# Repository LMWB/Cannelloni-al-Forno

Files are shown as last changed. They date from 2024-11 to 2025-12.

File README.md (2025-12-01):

# Cannelloni-al-Forno
Timer Clock Arduino Shield and C-Library

# Description
I always wanted to use the world famous LD293D motor driver IC. Here I created a very simple application using this chip to build a timer clock that is able to drive some 12V loads.  
Since the LD293D is a THT device and the overall application i quite simple, I decided to build the hole board as THT as it was back in the days :) To give the board a little retro touch I gave the top and bottom layer a hole grid pcb design.  

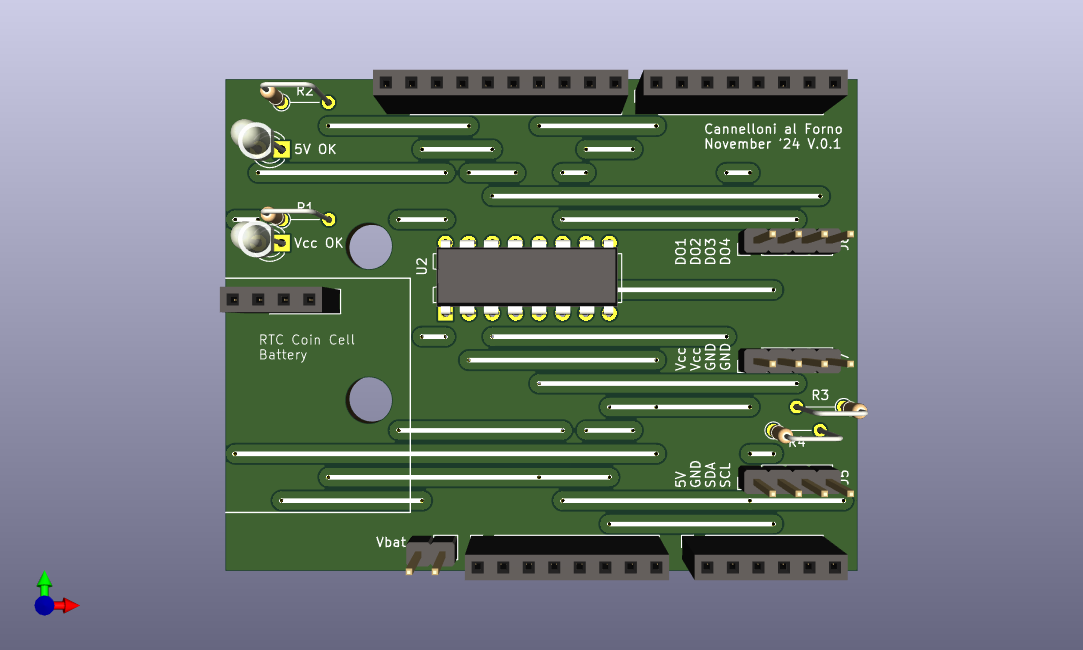
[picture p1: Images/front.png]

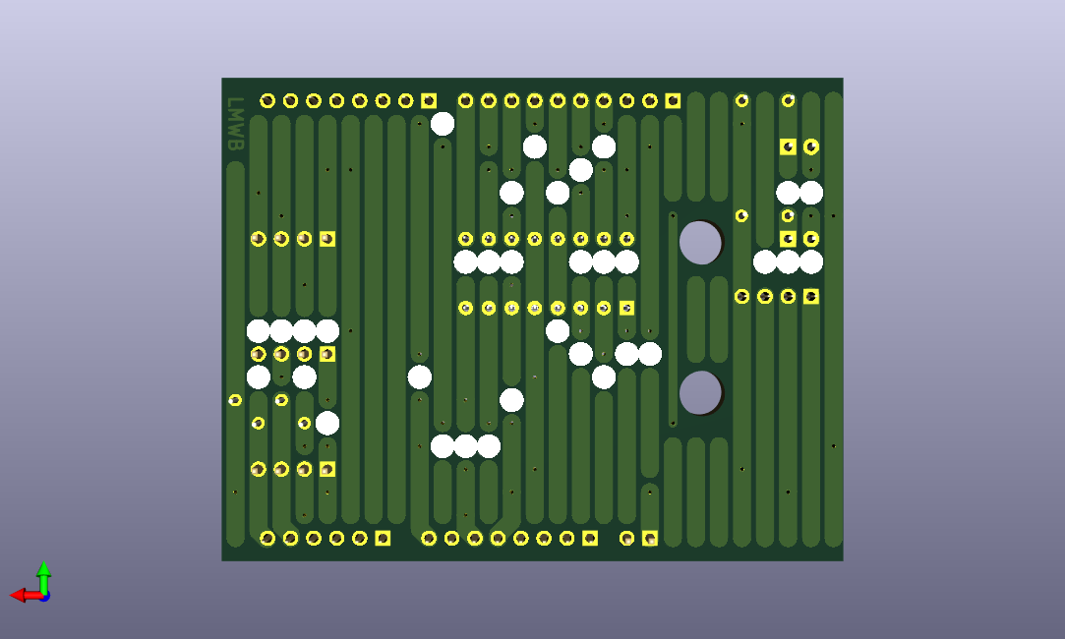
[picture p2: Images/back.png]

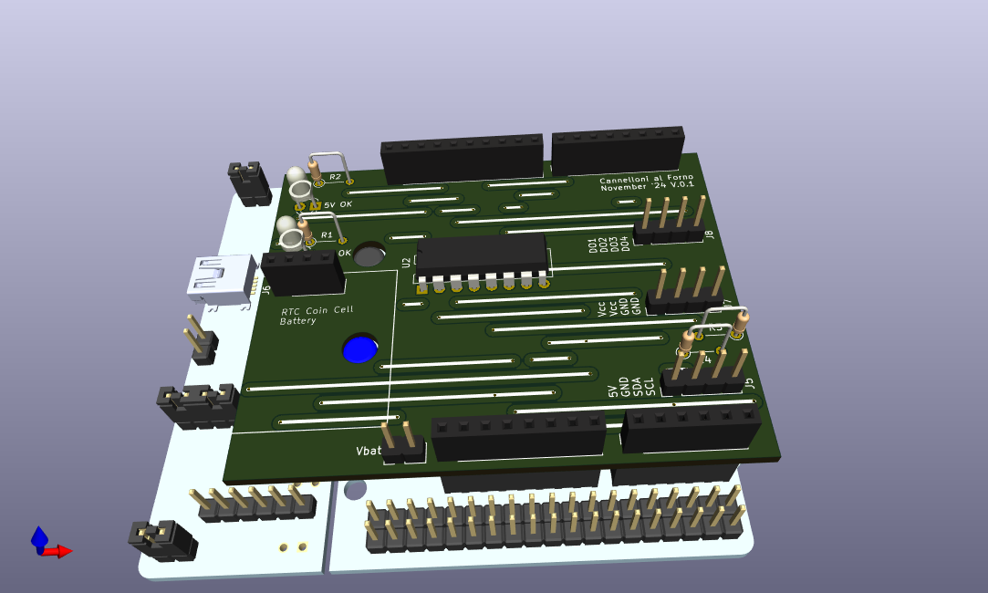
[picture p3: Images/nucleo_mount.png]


# Real World Example
I used the [led constant current driver](https://github.com/LMWB/LED_CC_Driver?tab=readme-ov-file) to create a light for my courtyard.  

todo
- Xmas deciration
- composition of Canneloni-al-Forno and LED_CC_Driver

# Features
- 12V input (powers Nucleo board as well)
- 4 digital outputs (Vout = Vinput)
- RTC with coin cell back up battery

# todo
- add some sort of remote access (wifi, can, RS485,..)
- add shunt to track total energy consumption
- use TI DRV89xx instead of LD293D
- update noRTOS to latest version
- make timerclock multi instance to control different output channels

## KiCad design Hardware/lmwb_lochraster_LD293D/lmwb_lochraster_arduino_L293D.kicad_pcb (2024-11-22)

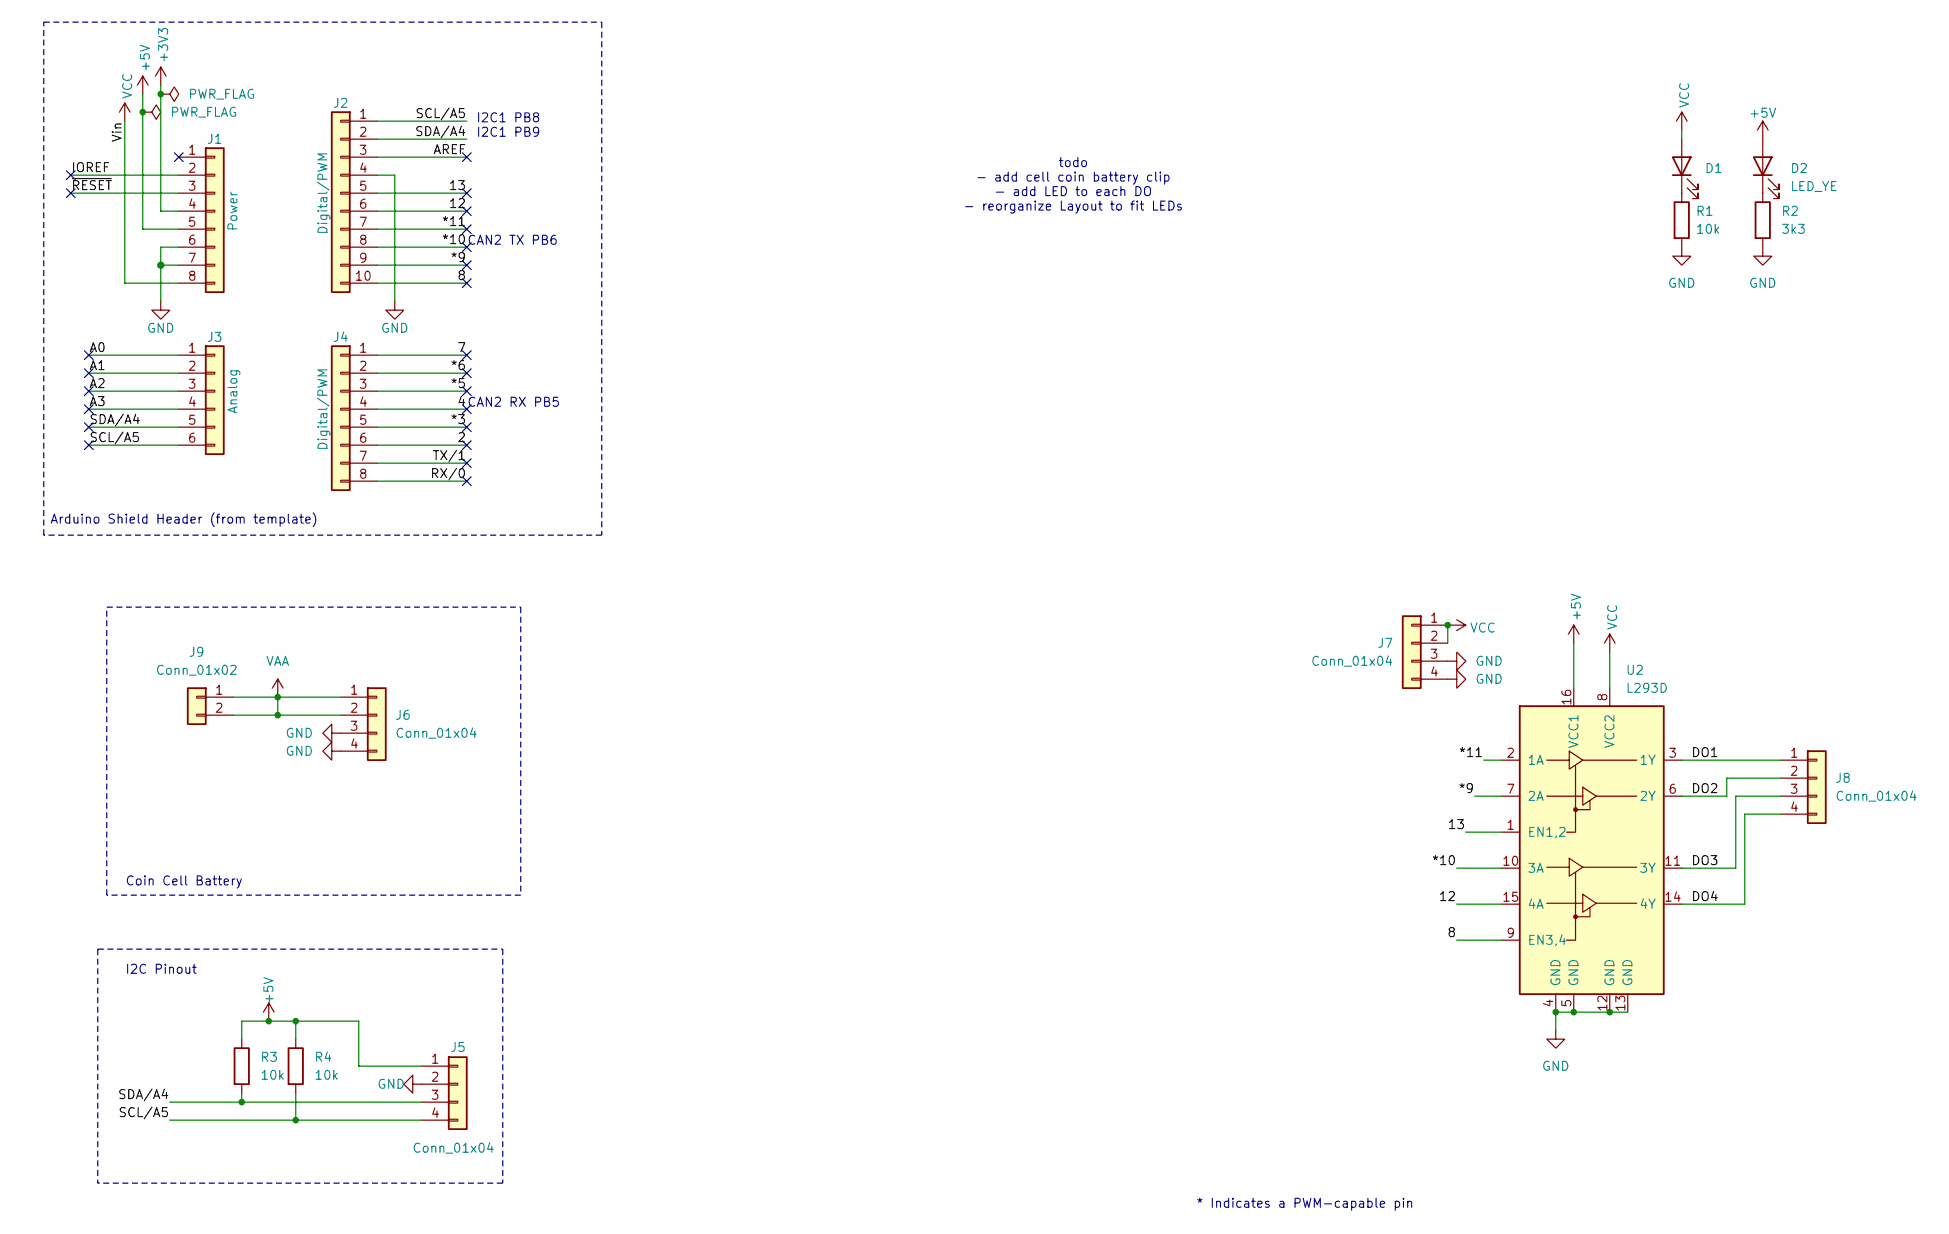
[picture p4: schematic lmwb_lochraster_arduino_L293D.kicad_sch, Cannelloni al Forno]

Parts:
D1, D2: LED_YE; LED_D3.0mm_Clear
J1: Power; PinSocket_1x08_P2.54mm_Vertical
J2: Digital/PWM; PinSocket_1x10_P2.54mm_Vertical
J3: Analog; PinSocket_1x06_P2.54mm_Vertical
J4: Digital/PWM; PinSocket_1x08_P2.54mm_Vertical
J5, J7, J8: Conn_01x04; PinHeader_1x04_P2.54mm_Vertical
J6: Conn_01x04; PinSocket_1x04_P2.54mm_Vertical
J9: Conn_01x02; PinHeader_1x02_P2.54mm_Vertical
R1, R3, R4: 10k; R_Axial_DIN0204_L3.6mm_D1.6mm_P5.08mm_Vertical
R2: 3k3; R_Axial_DIN0204_L3.6mm_D1.6mm_P5.08mm_Vertical
U2: L293D; DIP-16_W7.62mm

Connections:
+3V3: J1.4
+5V: D2.2 (A), J1.5, J5.1, R3.1, R4.1, U2.16 (VCC1)
/2: J4.6
/4: J4.4
/7: J4.1
/8: J2.10, U2.9 (EN3,4)
/12: J2.6, U2.15 (4A)
/13: J2.5, U2.1 (EN1,2)
/*3: J4.5
/*5: J4.3
/*6: J4.2
/*9: J2.9, U2.7 (2A)
/*10: J2.8, U2.10 (3A)
/*11: J2.7, U2.2 (1A)
/A0: J3.1
/A1: J3.2
/A2: J3.3
/A3: J3.4
/AREF: J2.3
/DO1: J8.1, U2.3 (1Y)
/DO2: J8.2, U2.6 (2Y)
/DO3: J8.3, U2.11 (3Y)
/DO4: J8.4, U2.14 (4Y)
/IOREF: J1.2
/RX/0: J4.8
/SCL/A5: J2.1, J3.6, J5.4, R4.2
/SDA/A4: J2.2, J3.5, J5.3, R3.2
/TX/1: J4.7
/~RESET: J1.3
GND: J1.6, J1.7, J2.4, J5.2, J6.3, J6.4, J7.3, J7.4, R1.2, R2.2, U2.4 (GND), U2.5 (GND), U2.12 (GND), U2.13 (GND)
unnamed: D1.1 (K), R1.1
unnamed: D2.1 (K), R2.1
VAA: J6.1, J6.2, J9.1, J9.2
VCC: D1.2 (A), J1.8, J7.1, J7.2, U2.8 (VCC2)

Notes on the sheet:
I2C1 PB8 I2C1 PB9
Coin Cell Battery
CAN2 RX PB5
todo - add cell coin battery clip - add LED to each DO - reorganize Layout to fit LEDs
CAN2 TX PB6
Arduino Shield Header (from template)
I2C Pinout
* Indicates a PWM-capable pin

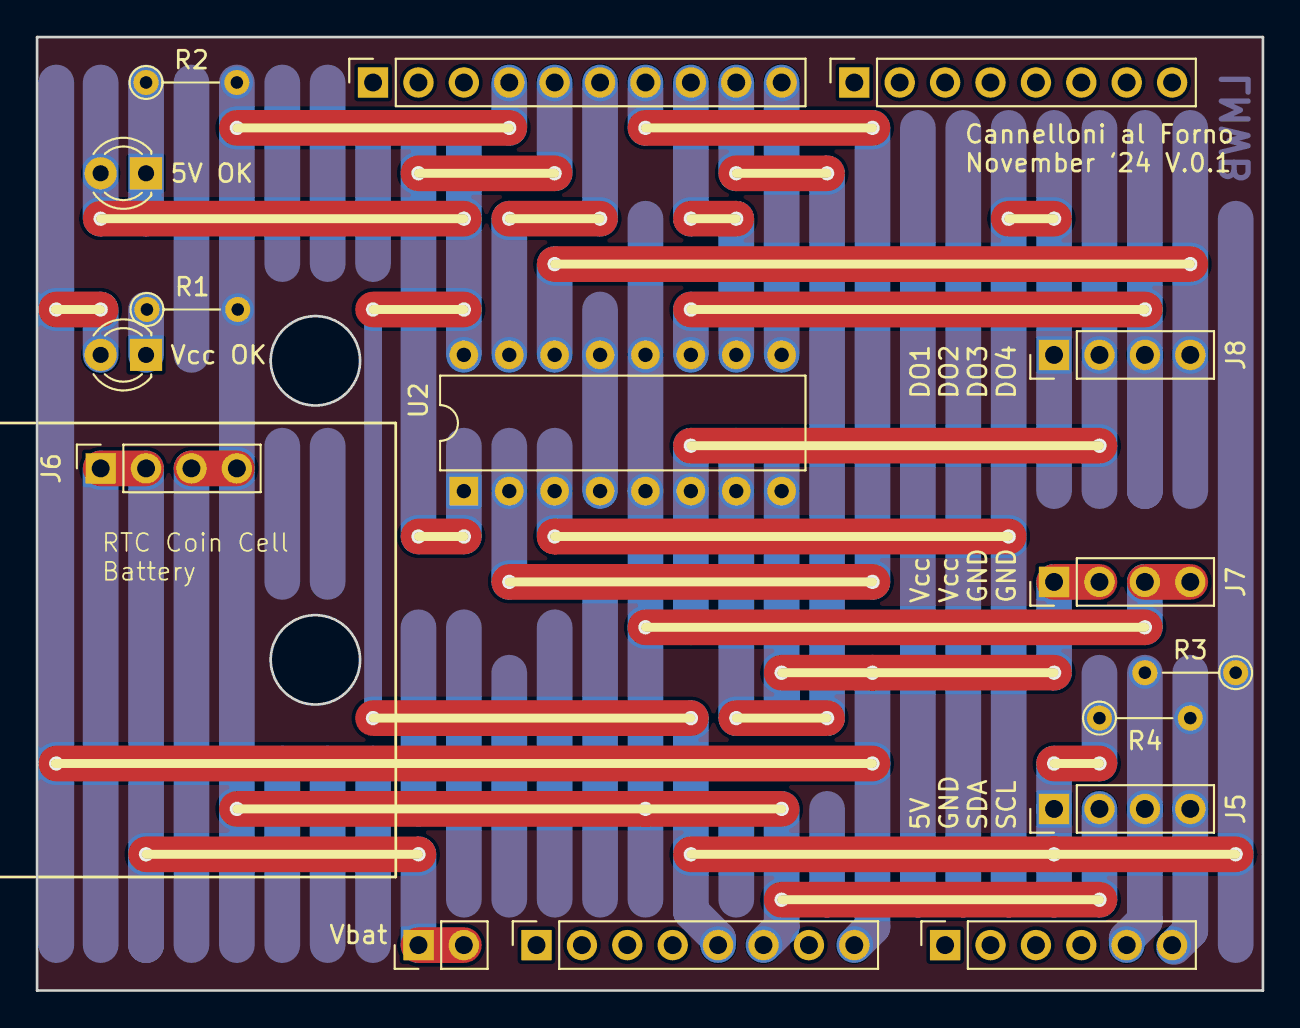
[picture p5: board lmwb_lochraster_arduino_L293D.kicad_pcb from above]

Board: 2 copper layers, 68.6 x 53.3 mm, 16 parts (0 on the bottom side), 18 nets.

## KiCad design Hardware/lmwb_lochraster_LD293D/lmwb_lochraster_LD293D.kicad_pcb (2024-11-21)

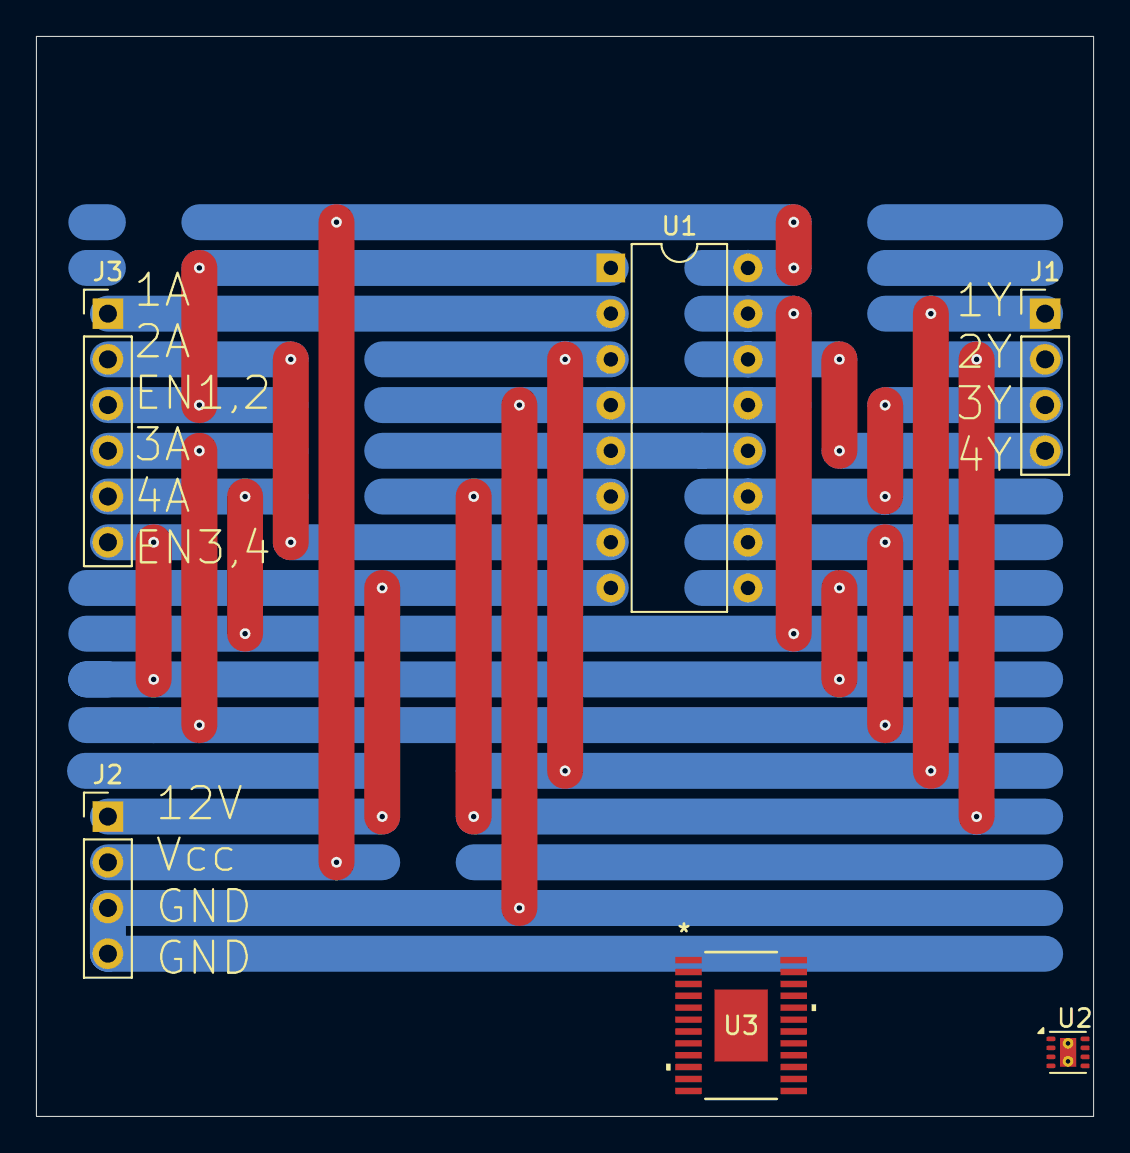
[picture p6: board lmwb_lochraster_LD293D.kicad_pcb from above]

Board: 2 copper layers, 58.7 x 60.0 mm, 6 parts (0 on the bottom side), 13 nets.

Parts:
J1, J2: Conn_01x04; PinHeader_1x04_P2.54mm_Vertical
J3: Conn_01x06; PinHeader_1x06_P2.54mm_Vertical
U1: L293D; DIP-16_W7.62mm
U2: DRV8212P; WSON-8-1EP_2x2mm_P0.5mm_EP0.9x1.6mm_ThermalVias
U3: DRV8908QPWPRQ1; PWP24_4P5X7P9_TEX

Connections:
+VDC: J2.1, U1.8 (VCC2)
GND: J2.3, J2.4, U1.4 (GND), U1.5 (GND), U1.12 (GND), U1.13 (GND)
unnamed: J1.1, U1.3 (1Y)
unnamed: J1.2, U1.6 (2Y)
unnamed: J1.3, U1.11 (3Y)
unnamed: J1.4, U1.14 (4Y)
unnamed: J3.1, U1.2 (1A)
unnamed: J3.2, U1.7 (2A)
unnamed: J3.3, U1.1 (EN1,2)
unnamed: J3.4, U1.10 (3A)
unnamed: J3.5, U1.15 (4A)
unnamed: J3.6, U1.9 (EN3,4)
VCC: J2.2, U1.16 (VCC1)

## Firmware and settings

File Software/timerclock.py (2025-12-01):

import serial
import time
import argparse
'''
parse current time in linux format to uart to microcontroller 

from terminal: 'python timerclock.py /dev/ttyACM0'

'''
def date_time_parser(args):
	# generate time string in format like __TIME__(19:10:12) and __DATE__ (Oct 20 24) under C language
	
	# use this for UTC time
	now = time.gmtime()

	# use this for local time (summer / winter)
	#now = time.localtime()
	
	atCommandString = "AT+SETRTC="
	timeString = time.strftime("%H:%M:%S", now)
	dateString = time.strftime("%b %d %Y", now)
	atCommandString = atCommandString + timeString + ' '
	atCommandString = atCommandString + dateString
	atCommandString = atCommandString + '\r\n'
	print(atCommandString)
	serialInterface = args.serial_interface
	try:
		byteString = atCommandString.encode()
		terminal = serial.Serial(serialInterface, 115200)
		terminal.write(byteString)
		answer = terminal.readline()
		print(f'received:{answer}')
		terminal.close()
	except:
		print(f'could not open port {serialInterface} Device or resource busy')
		return 0
	return 1

if __name__ == "__main__":
	
	parser = argparse.ArgumentParser()
	parser.add_argument('serial_interface', type=str, help='COMx on windows or /dev/ttyACM0 on linux')
	args = parser.parse_args()
	
	if(date_time_parser(args)):
		print('RTC set successfully')
	else:
		print('Failed to set RTC')

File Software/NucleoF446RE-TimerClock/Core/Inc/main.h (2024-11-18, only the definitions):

#define B1_Pin GPIO_PIN_13
#define B1_GPIO_Port GPIOC
#define B1_EXTI_IRQn EXTI15_10_IRQn
#define USART_TX_Pin GPIO_PIN_2
#define USART_TX_GPIO_Port GPIOA
#define USART_RX_Pin GPIO_PIN_3
#define USART_RX_GPIO_Port GPIOA
#define EN1_2_Pin GPIO_PIN_5
#define EN1_2_GPIO_Port GPIOA
#define Out4_Pin GPIO_PIN_6
#define Out4_GPIO_Port GPIOA
#define Out1_Pin GPIO_PIN_7
#define Out1_GPIO_Port GPIOA
#define Out2_Pin GPIO_PIN_7
#define Out2_GPIO_Port GPIOC
#define EN3_4_Pin GPIO_PIN_9
#define EN3_4_GPIO_Port GPIOA
#define TMS_Pin GPIO_PIN_13
#define TMS_GPIO_Port GPIOA
#define TCK_Pin GPIO_PIN_14
#define TCK_GPIO_Port GPIOA
#define SWO_Pin GPIO_PIN_3
#define SWO_GPIO_Port GPIOB
#define Out3_Pin GPIO_PIN_6
#define Out3_GPIO_Port GPIOB

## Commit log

2024-11-05 added project for STM32-L476
2024-11-05 include libs to STM32-L476 project
2024-11-09 changed uart2 to interrupt base without DMA
2024-11-18 update cubeMX .ioc file to match LD293 arduino shield
2024-11-18 update main.c (F446RE Part) to match LD293 arduino shield
2024-11-21 add hardware kicad files, minor changes in software/noRTOS
    [lmwb_lochraster_LD293D.kicad_pcb, lmwb_lochraster_LD293D.kicad_sch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]
2024-11-22 added images and update readme
    [lmwb_lochraster_arduino_L293D.kicad_pcb]
2024-12-12 rename some timer utils
2025-11-30 started PR to trace changes

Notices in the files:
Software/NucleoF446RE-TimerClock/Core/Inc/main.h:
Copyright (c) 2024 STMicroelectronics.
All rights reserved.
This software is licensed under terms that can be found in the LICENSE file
